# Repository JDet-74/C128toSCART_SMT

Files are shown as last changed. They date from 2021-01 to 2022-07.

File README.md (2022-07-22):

# C128toSCART_SMT
<h2>A further in SMT developed Version of the C128toSCART_THT project.</h2>
<p>It is a second version of the SMT variant with only a few THT components left.</p>
<hr />
<p>You can watch a short intruduction video on YouTube -> <a href="https://youtu.be/qOvFwwrAEIk" target="_blank">C128toSCART_SMT</a></p>
<p>The quality depends on the SCART display device. Make sure that the SCART input of your display device provides RGB, CVBS (composite) or S-Video (Luma & Chroma).</p>
<hr />
<h2>Boards but no housings available</h2>
<p>I currently have boards but no housings in stock. Use the issue tracking system to get in touch with me. <br />
Fortunately Markus designed a housing and gave me the STL Files for 3D printing. A big thankyou to Markus R.</p>

<hr />
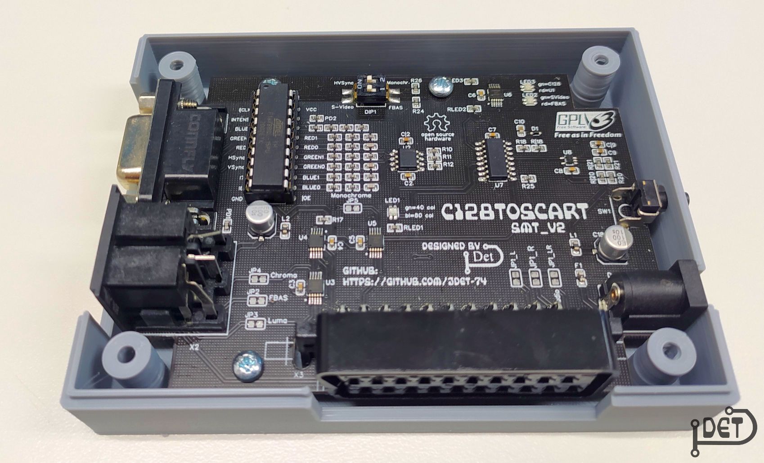
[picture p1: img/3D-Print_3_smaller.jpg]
3D-Print_3_smaller

<hr />
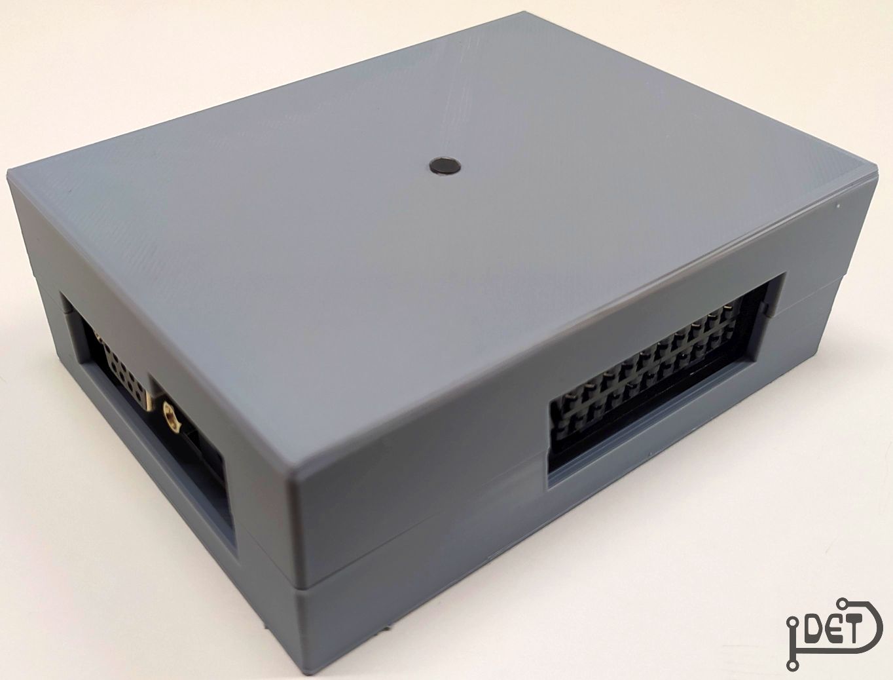
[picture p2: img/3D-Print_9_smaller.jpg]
3D-Print_9_smaller

<hr />

<p>You can find the STL files in the 3D_print folder. <br /> 
Take a look into the <strong>manual</strong> and the <strong>set_prices_shipping</strong> PDFs for more information.</p>

<hr />
<p>After some of the boards I have ordered have been sold, I will make all project data available here.</p> 
<p>The project can then be ordered with the <strong>GERBER, BOM and PNP</strong> files directly from JLCPCB.
JLCPCB offers an <strong>"SMT Assembly Service"</strong>.</p>
<p>All the files can then be found in the <strong>pcb_fabrication</strong> folder.</p>
<p>&nbsp;</p>
<p>Greetz<br /><br />JDet</p>

## Contact
For any questions (technical / experience), please use the issue tracking system of github. 

<hr />
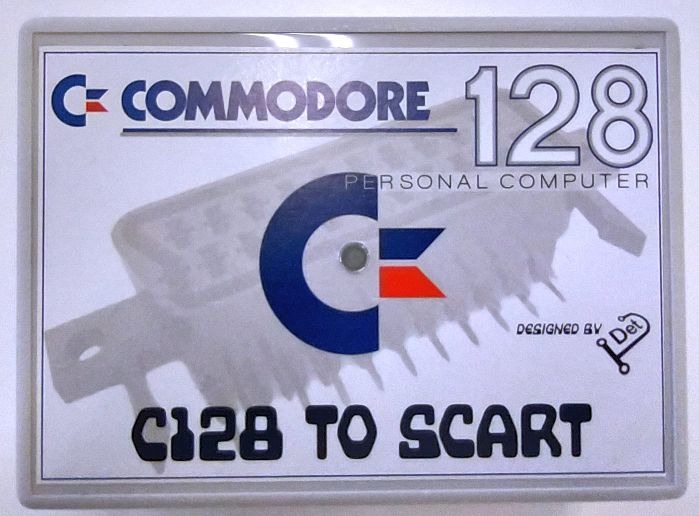
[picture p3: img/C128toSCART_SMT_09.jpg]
C128toSCART_SMT_09

<hr />
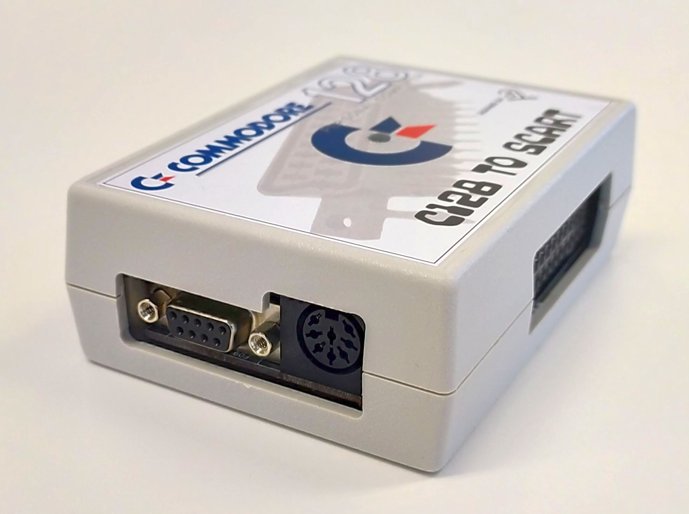
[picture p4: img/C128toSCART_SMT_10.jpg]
C128toSCART_SMT_10

<hr />
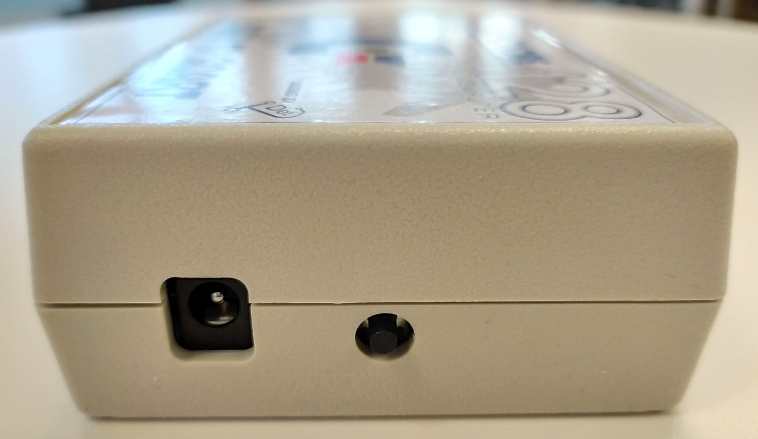
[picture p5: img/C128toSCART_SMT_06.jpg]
C128toSCART_SMT_06

<hr />
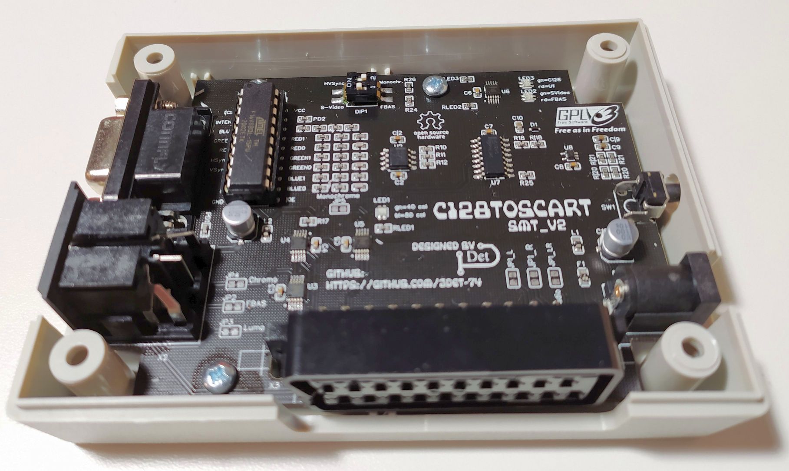
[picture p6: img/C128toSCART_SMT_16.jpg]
C128toSCART_SMT_16

<hr />
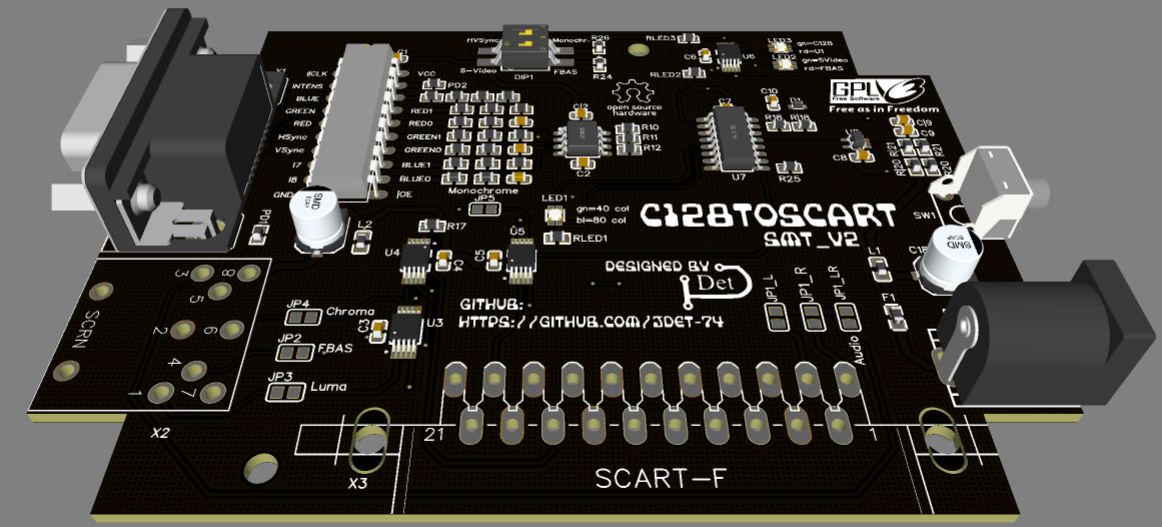
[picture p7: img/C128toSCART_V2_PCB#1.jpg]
C128toSCART_SMT_V2_PCB#1

<hr />
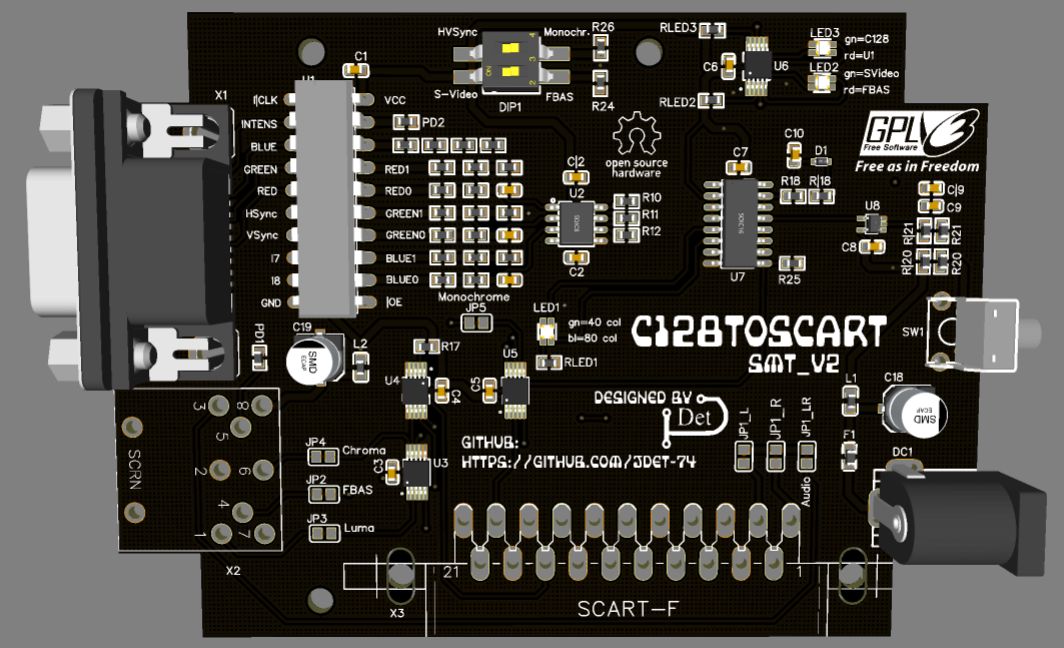
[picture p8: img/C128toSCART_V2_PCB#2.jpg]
C128toSCART_SMT_V2_PCB#2

<hr />
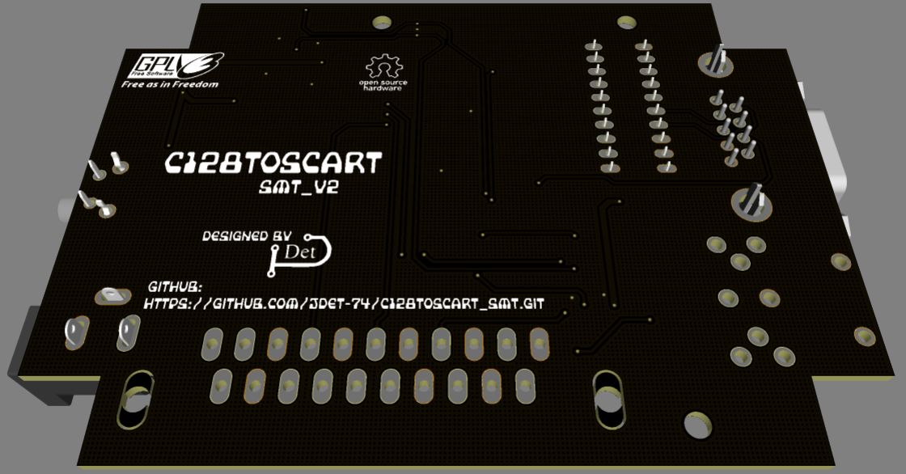
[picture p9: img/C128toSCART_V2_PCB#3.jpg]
C128toSCART_SMT_V2_PCB#3


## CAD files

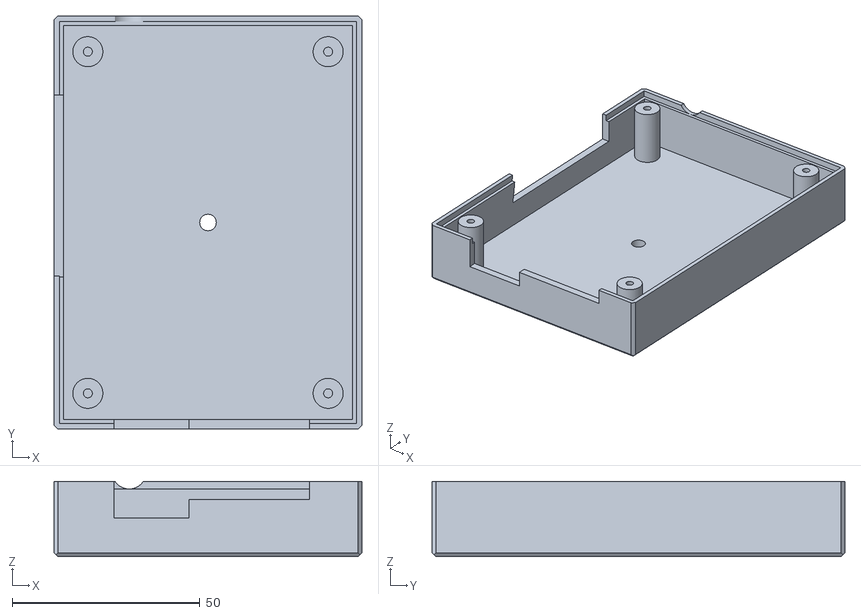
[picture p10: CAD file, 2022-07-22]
3D_pint/housing_top_v7.stl
82.0 x 110.0 x 20.0

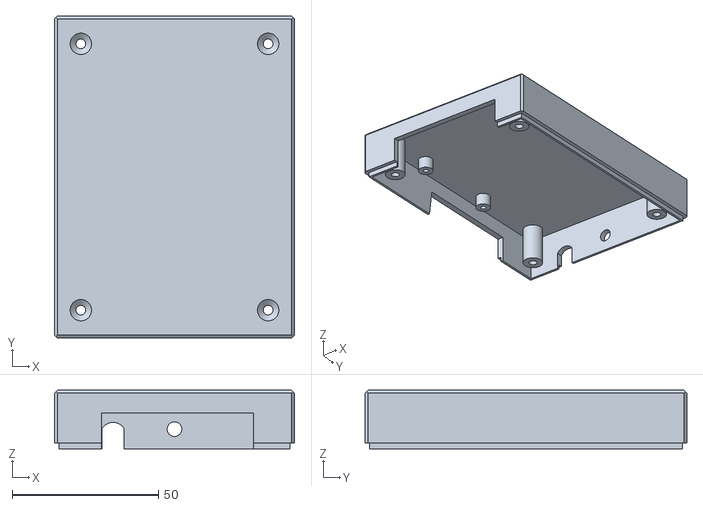
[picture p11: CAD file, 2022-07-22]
3D_pint/housing_bottom_v7.stl
82.0 x 110.0 x 20.0

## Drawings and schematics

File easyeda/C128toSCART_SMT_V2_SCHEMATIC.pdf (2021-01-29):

The CONTROL section is responsible for the 40 col. or 80 col. mode or composite / s-video mode. VCC

VIDEO_MODE (default FBAS) | 40/80_COL_MODE (default 40 col.) | SYNC_MODE (default Monochrome)

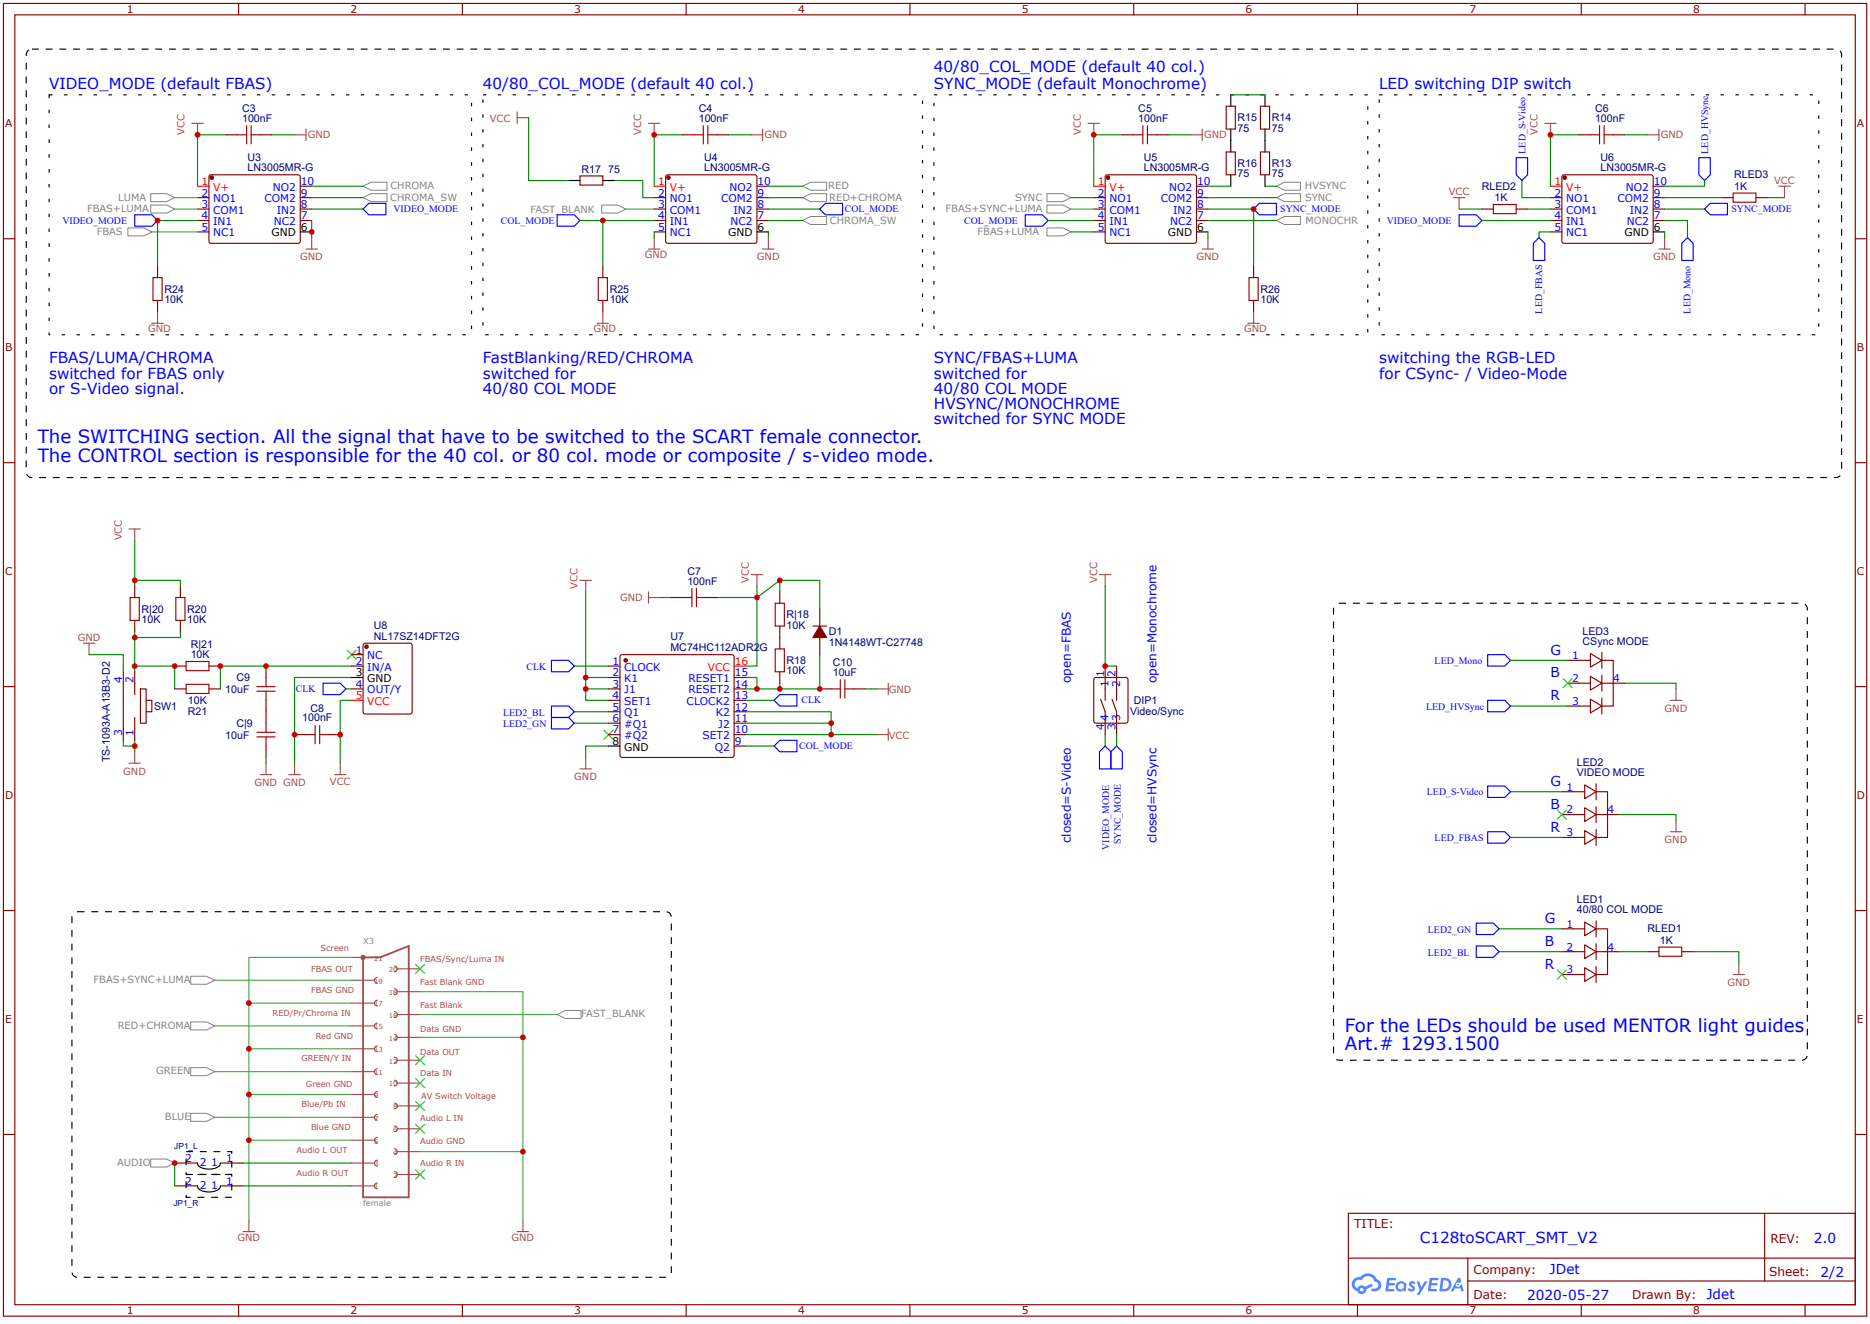
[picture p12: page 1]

LED switching DIP switch

FBAS/LUMA/CHROMA
switched for FBAS only
or S-Video signal.

SYNC/FBAS+LUMA
switched for
40/80 COL MODE
HVSYNC/MONOCHROME
switched for SYNC MODE

switching the RGB-LED
for CSync- / Video-Mode

The SWITCHING section. All the signal that have to be switched to the SCART female connector.

FBAS/Sync/Luma IN

RED/Pr/Chroma IN

For the LEDs should be used MENTOR light guides
Art.# 1293.1500

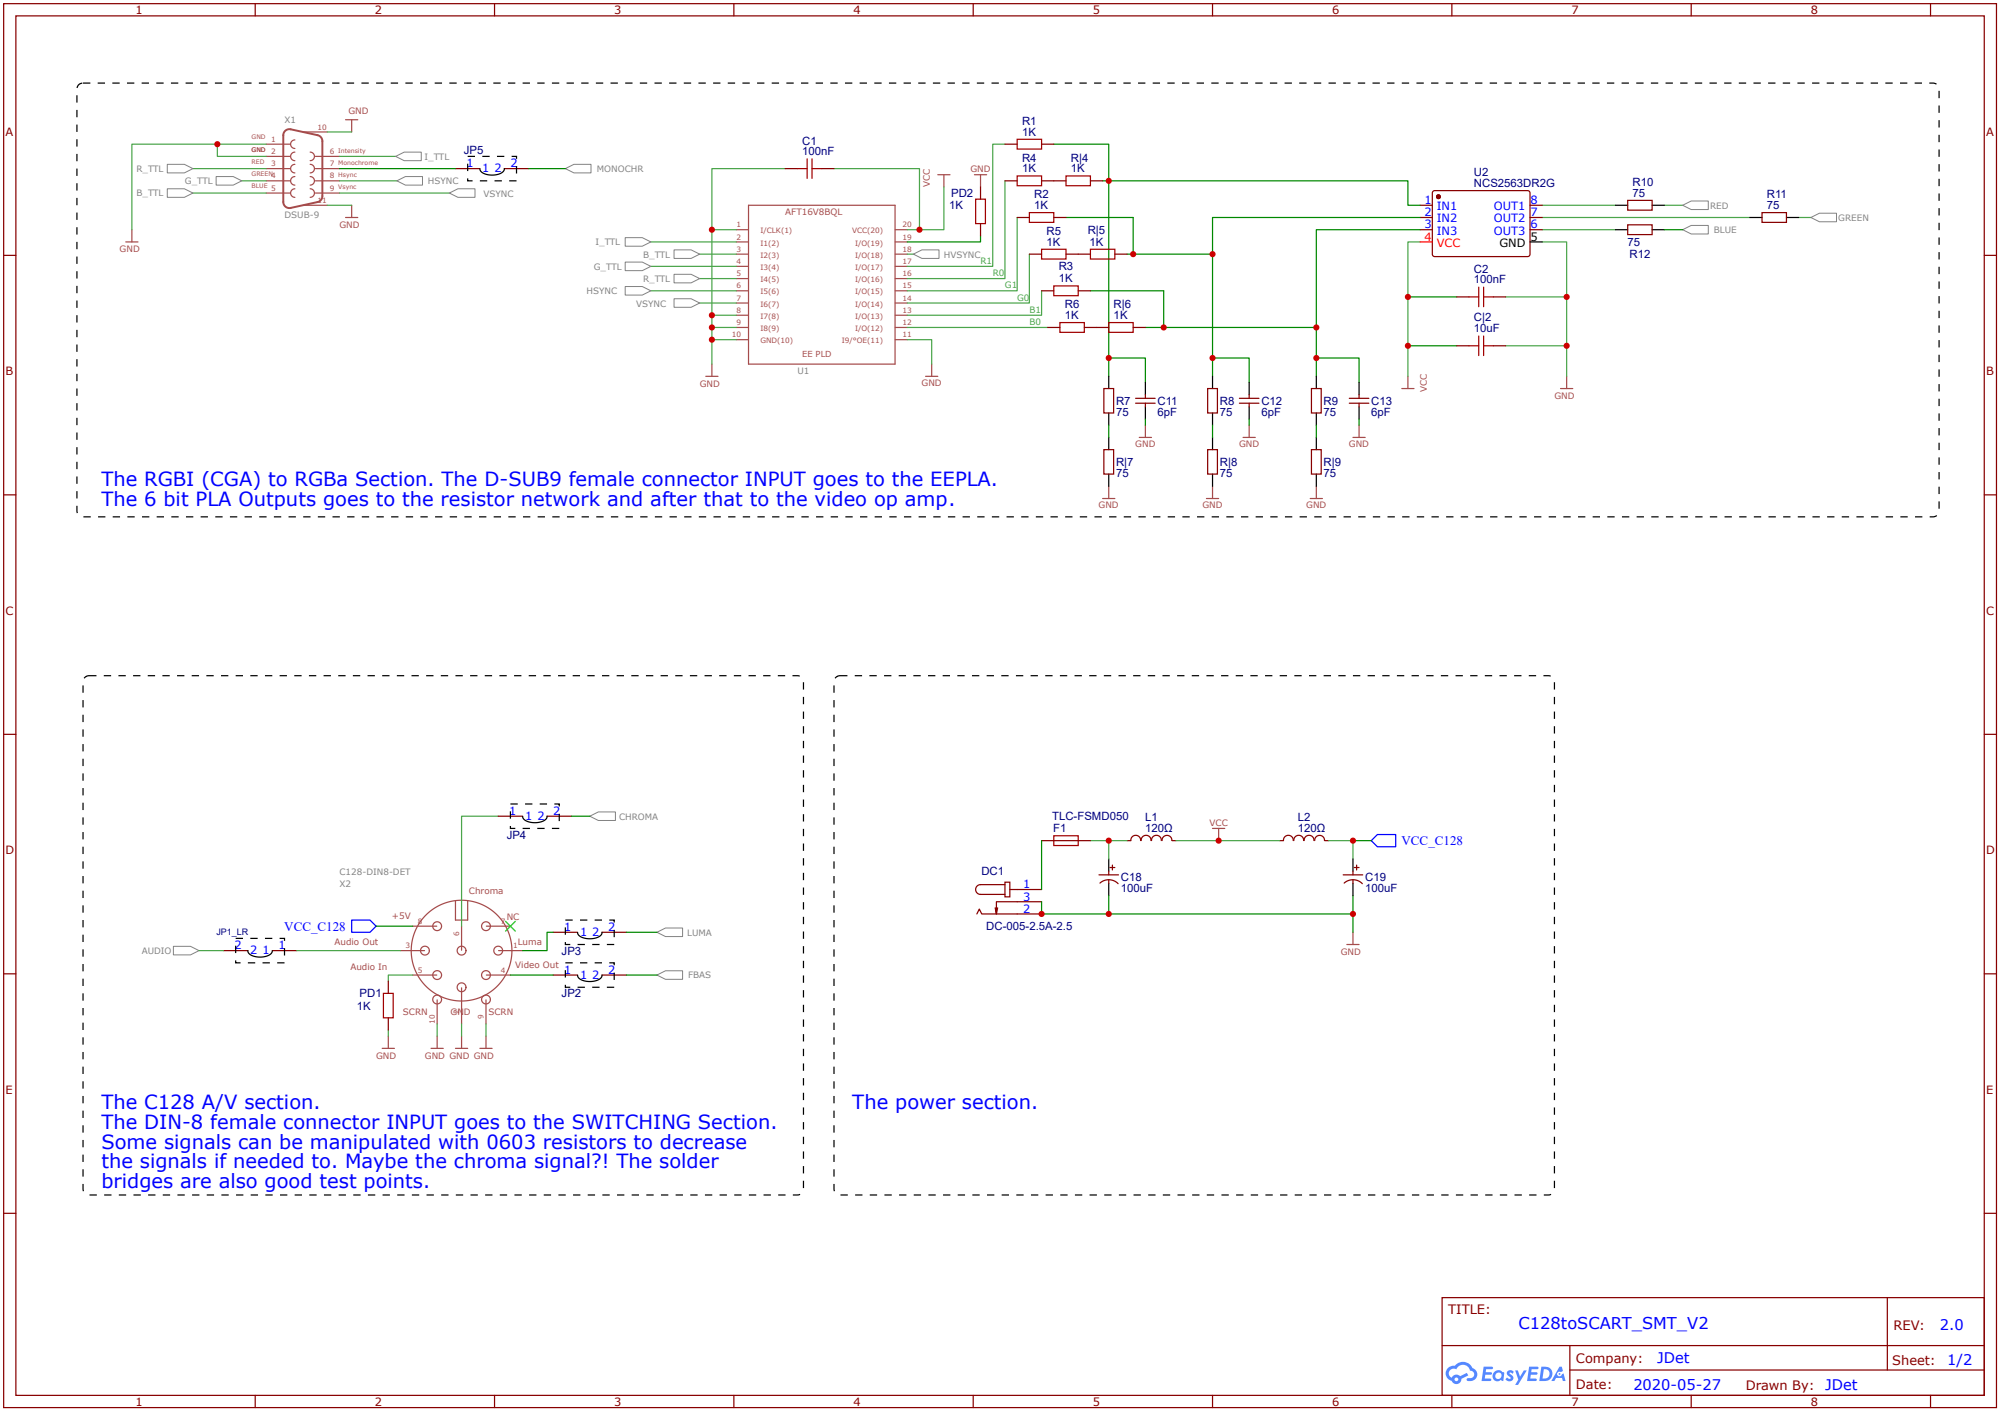
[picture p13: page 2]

The RGBI (CGA) to RGBa Section. The D-SUB9 female connector INPUT goes to the EEPLA.
The 6 bit PLA Outputs goes to the resistor network and after that to the video op amp.

The C128 A/V section.
The DIN-8 female connector INPUT goes to the SWITCHING Section.
Some signals can be manipulated with 0603 resistors to decrease
the signals if needed to. Maybe the chroma signal?! The solder
bridges are also good test points.

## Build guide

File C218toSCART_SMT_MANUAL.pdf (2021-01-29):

# C128toSCART_SMT

## https://github.com/JDet-74/C128toSCART_SMT.git

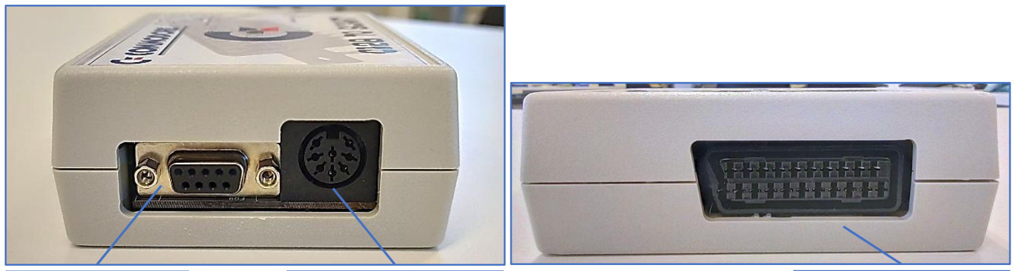
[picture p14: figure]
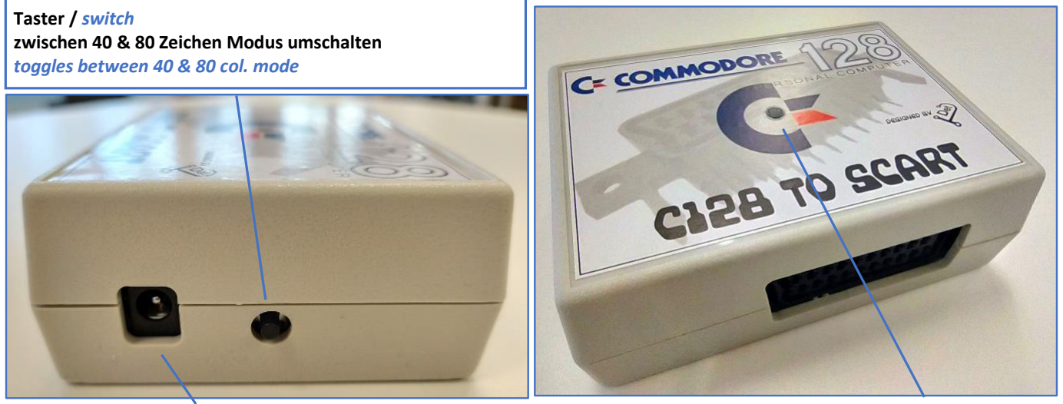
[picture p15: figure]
Taster / switch; toggles between 40 & 80 col. mode
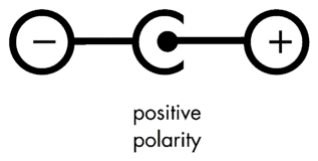
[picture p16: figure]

C128to SCART_THT | Seite: 1 von 4
Bedienungsanleitung | Manual

## DEMO Video → https://youtu.be/qOvFwwrAEIk

### ÜBERSICHT OVERVIEW

### SUB-D-9 Buchse, DIN-8(262°) Buchse und SCART Buchse

### SUB-D-9 socket, DIN-8(262°) socket and SCART socket

### 2,1mm Hohlstecker Buchse, Taster

### 2,1mm barrel jack, tactical switch

SUB-D-9
RGBI/CGA
Eingang / input

DIN-8(262°)
Video / Sound / Power
Eingang / input

SCART
Video / Sound
Ausgang / output

2,1mm Hohlstecker / 2,1 mm barrel jack
+5V/400mA abgreifbar, wenn der C128 an der DIN8 angeschlossen ist
+5V/60mA einspeisen, wenn nur der RGBI/CGA Eingang im 80 Zeichen Modus genutzt wird Supplies +5V/400mA, if the C128 is plugged into the DIN8 socket.
Connect +5V/60mA, if just the RGBI/CGA input in the 80 col. mode is connected.

zwischen 40 & 80 Zeichen Modus umschalten

LED
Grün = 40 Zeichen Modus
Blau = 80 Zeichen Modus
Green = 40 col. mode
Blue = 80 col. mode

## https://github.com/JDet-74/C128toSCART_SMT.git

### Anschließen eines C128 connecting a C128

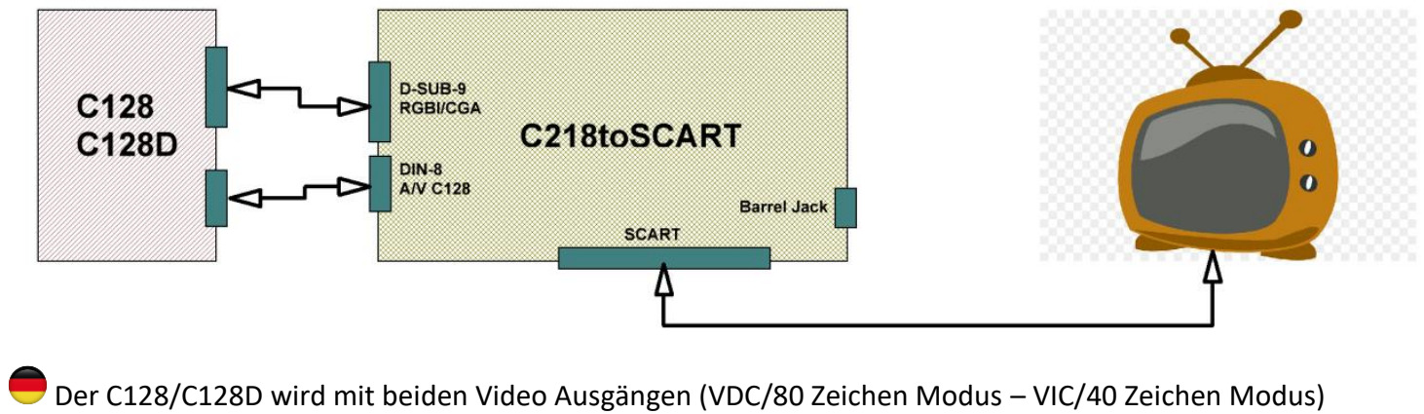
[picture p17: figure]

Der C128/C128D wird mit beiden Video Ausgängen (VDC/80 Zeichen Modus – VIC/40 Zeichen Modus) angeschlossen. Der SCART Ausgang wird über das SCART Kabel mit dem Anzeige Gerät verbunden.

Connect the C128/C128D with both video outputs (VDC/80 col. Mode – VIC/40 col. Mode). Connect the SCART Output with your display device.

### nutzen eines SCART2HDMI Adapters using a SCART2HDMI converter

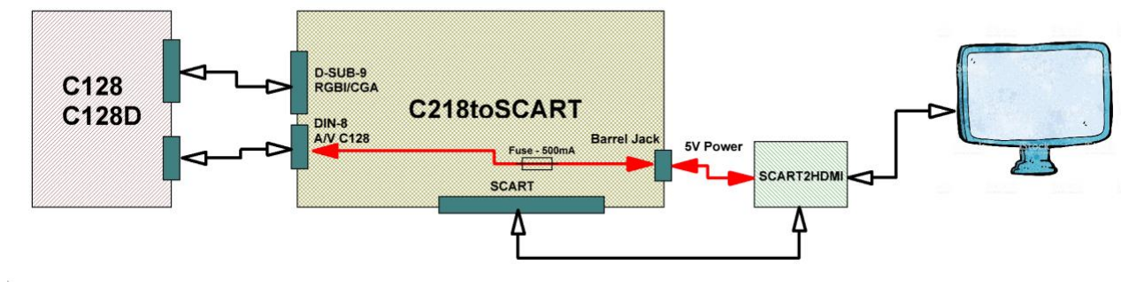
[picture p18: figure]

Wenn der Adapter 5V/400mA nicht überschreitet, kann er an die Hohlsteckerbuchse angeschlossen warden

If the converter doesn’t drain more than 5V/400mA, you can connect it to the barrel jack.

DIP Schalter / DIP switch
HVSync: das von U1 generierte Csync Signal wird für den 80 Zeichen Modus genutzt. (LED3=rot) Monochr.: das vom C128 generierte Csync Signal wird für den 80 Zeichen Modus genutzt. (LED3=grün) Wenn ein C128 angeschlossen ist, sollten beide Einstellungen funktionieren.
HVsync: the U1 generated signal is used for the 80 col. mode (LED3=red)
Monochr.: the C128 generated Csync signal is used fort he 80 col. mode (LED3=green)
If a C128 is connected, both settings schould be fine.
S-Video: das Luma & Chroma Signal des 40 Zeichen Modus wird genutzt. (LED2=grün) FBAS: das CVBS/Composite Signal des 40 Zeichen Modus wird genutzt (LED2=rot) S-Video: the Luma & Chroma signal of the 40 col. mode are used. (LED2=green FBAS: the CVBS/composite signal of the 40 col. mode is used. (LED2=red)

## https://github.com/JDet-74/C128toSCART_SMT.git

### Anschließen eines CGA Gerätes connecting a CGA outputting device

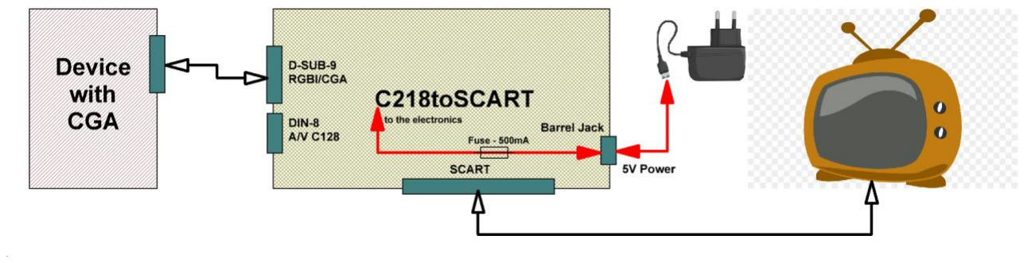
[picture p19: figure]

Verbinde den CGA Ausgang mit dem SUB-D-9 Eingang und schließe +5V an die Hohlstecker Buchse an.

Verbinde mit dem SCART Kabel das Anzeige Gerät und schalte auf den 80 Zeichen Modus (BLAUE LED).

Connect the CGA device with the SUB-D-9 input and connect a +5V PSU to the barrel jack. Connect your display device with the SCART cable and switch to the 80 col. Mode (BLUE LED).

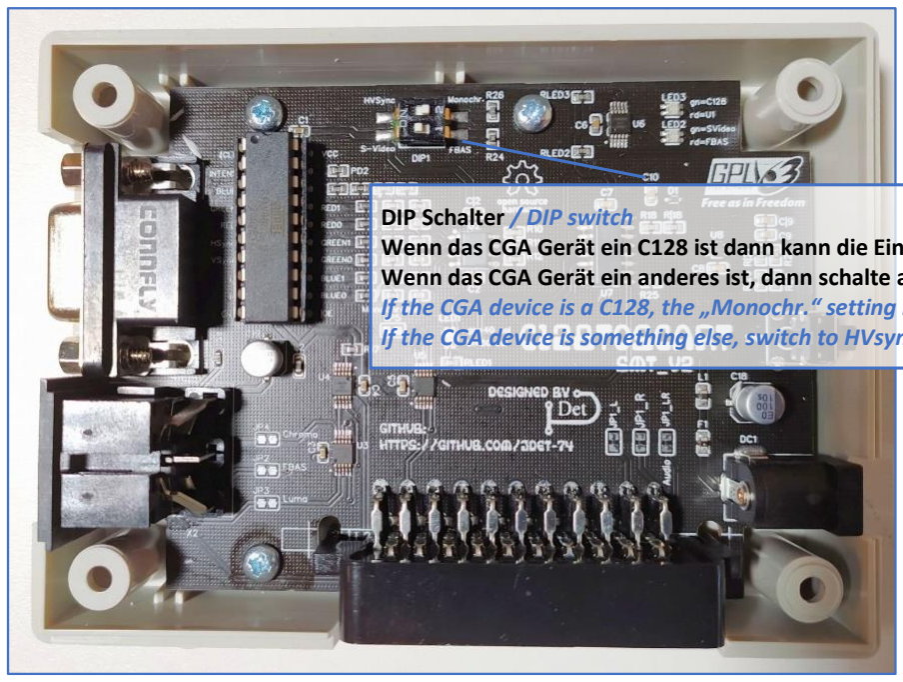
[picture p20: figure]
DIP Schalter / DIP switch
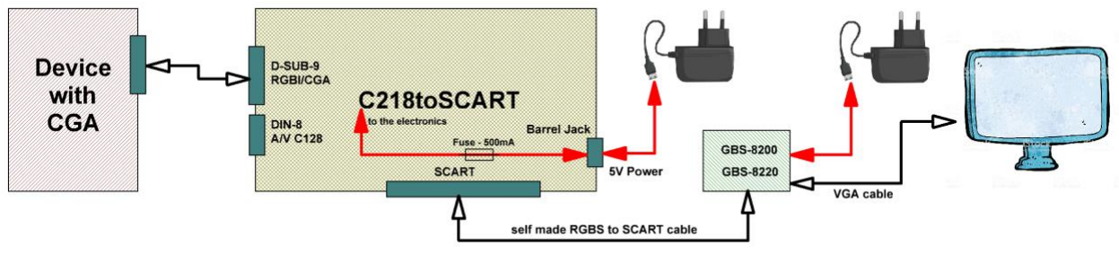
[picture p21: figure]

Es kann auch ein GBS-8200/8220 genutzt werden, um einen Monitor mit VGA Anschluss zu nutzen. Hierzu muss ein spezielles Kabel hergestellt werden.

you can also use a GBS-8200/8220 to connect a Monitor with a VGA input. For this application you have to solder a special RGBS to SCART cable.

Wenn das CGA Gerät ein C128 ist dann kann die Einstellung auf „Monochr.“ bleiben. (LED3=grün) Wenn das CGA Gerät ein anderes ist, dann schalte auf HVsync. (LED3=rot)
If the CGA device is a C128, the „Monochr.“ setting is fine. (LED3=green)
If the CGA device is something else, switch to HVsync. (LED3=red)

## https://github.com/JDet-74/C128toSCART_SMT.git

### verbindet das GBS-8200/8220 connects a GBS-8200/8220

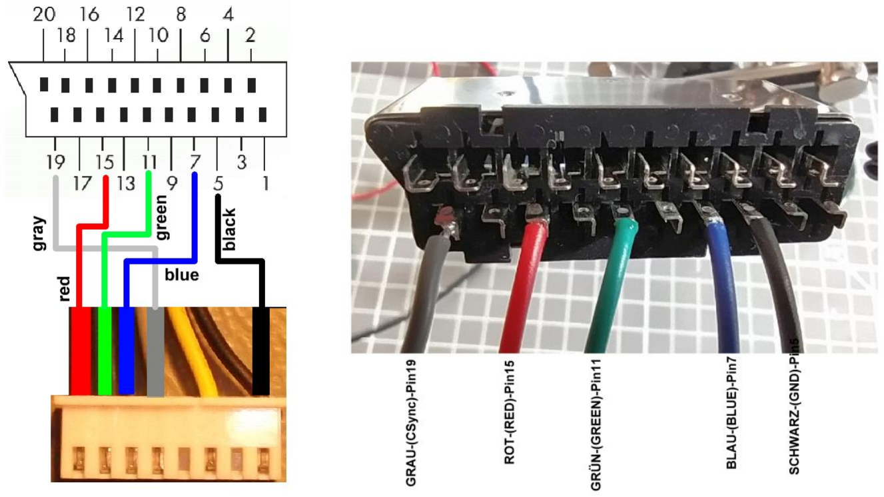
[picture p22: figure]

Löte das Kabel der GBS-8200/8220 wie abgebildet an einen SCART Stecker.

solder the GBS-8200/8220 cable to a SCART plug like in the pictures.

### mehr Optionen more options

Lötbrücken / solder bridges
Man kann die Lötbrücken trennen (aufschneiden) und SDM 0603 Widerstände in die Signale (Chroma, Luma, FBAS) einlöten, um das Signal zu schwächen. Bei Chroma wird oft empfohlen einen 330 Ohm Widerstand einzulöten, da neuere TV Geräte schwächere Signale bevorzugen.
The solder bridges can be separated (cut open) and SDM 0603 resistors can be soldered into the signals (Chroma, Luma, FBAS) to weaken the signal. With Chroma it is often recommended to use a 330 ohm resistor, since newer TV sets prefer weaker signals.

Lötbrücken / solder bridges
Die Signale des Tonsignals (Mono) können ebenso manipuliert werden.
The sound singnals can also be manipulated like the video signals.

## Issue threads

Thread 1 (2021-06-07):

any left for selling ?

Bragir, 2021-06-07:
Do you have any left for selling ?
If so then i would like to buy an option 3 (the complete finished and tested adapter)
and one of each of the cables (din-8, sub-d-9 and scart cable)
option 3             -  38.00€
din8                    -    9.00€
sub D9               -     3.00€
Scart                  -     2.00€
Shipment(EU)   -    15.00€

total                  -    67.00€

JDet-74, 2021-06-07:
Hey @Bragir
I have to build some devices.
Currently, I am out of stock :)
Where do you live?
Maybe the shipping costs are cheaper.
Please send a mail to kernelpanic_74@yahoo.de with your address.

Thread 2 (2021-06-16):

Hey rockstar..

Paulie420, 2021-06-16:
I’d love to grab a full complete c=128 to scart, a scart cable and a serial cable.

I’m in Portland, Oregon, USA And think shipping is 31. I can up with 77 or so, but I’d love to order and pay if you’re in mood to make some smoke.

JDet-74, 2021-06-16:
Hey @Paulie420

I've just made a couple of C128toSCART devices again.
Unfortunately, the DIN8 cables are currently out. I have to order this again first. I know a guy who soldered them for 9 EUR.
If you only want the C128toSCART device, the D-SUB9 cable and the SCART cable, then I can send everything to you immediately.
The shipping costs to the USA are ridiculously expensive at the moment.
In the middle of March, I sent a package to Adrian Black (https://www.youtube.com/user/craig1black) in Portland. That was a 2kg (70.54792 Oz) package and cost 20 EUR. I have to clarify what the cheapest shipping option to the USA is. The package will only weigh around 500g (17.63698 Oz) and it will likely be cheaper. Do you want a shipping method that is trackable or not?
Send me a message to kernelpanic_74@yahoo.de with your address and I will send everything to you.

Paulie420, 2021-06-19:
the DIN8 cable is just... a DIN8 cable on both ends? i could prolly order on amazon??? emailing you

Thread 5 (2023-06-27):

Board + Kabel x 2

DoubleA-WTH, 2023-06-27:
Hallo,

hätte Interesse an einem Board und den Din8 + RGB9 Kabeln.
Egal ob Bausatz oder fertig. Gehäuse kann ich selber drucken.

Danke und VG
Andreas

JDet-74, 2023-09-11:
all done ...

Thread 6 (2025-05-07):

Interest in the StatTrak Module

LIT1705, 2025-05-07:
Hi Fantonrko,

I saw your StatTrak module on YouTube and I’d like to buy it. Is there any way to get in touch with you?

I noticed today that you’ve taken the video offline — if you’re no longer offering the module, I’d really appreciate it if you could share the files so I can build it myself.

Thanks in advance.

LIT

Closed 2025-05-07.
